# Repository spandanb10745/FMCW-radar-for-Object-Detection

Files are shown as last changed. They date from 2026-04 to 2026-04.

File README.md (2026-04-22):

# FMCW Radar for Object Detection 📡

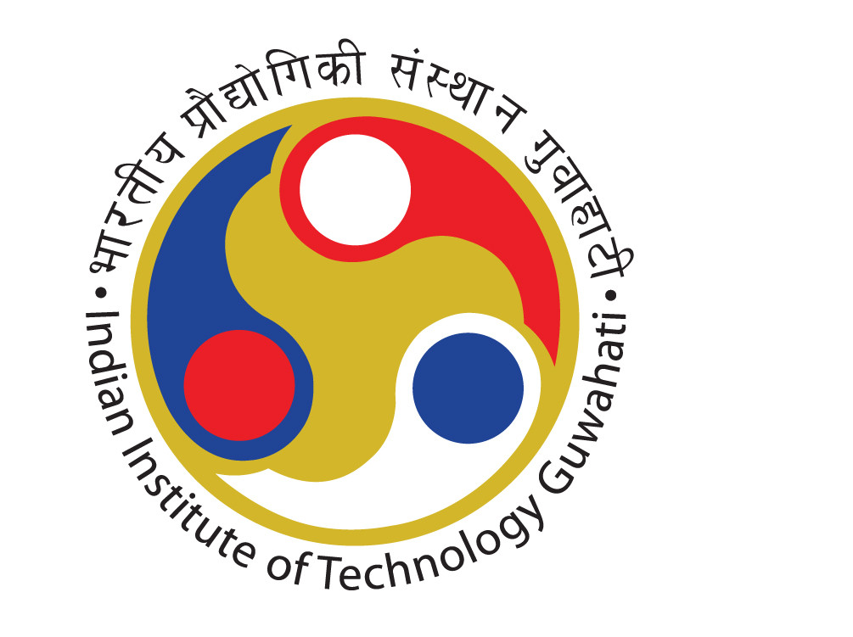
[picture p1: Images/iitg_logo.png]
IITG Logo

*Department of Electronics and Communication Engineering, Indian Institute of Technology, Guwahati*

This repository contains the hardware design, theoretical models, and digital signal processing (DSP) algorithms for a custom-built Frequency-Modulated Continuous Wave (FMCW) radar. The system is designed to detect both stationary distances and track moving targets (human radial velocity) using a 2.4 GHz center frequency.

## 📋 Table of Contents
* [Overview & Principles](#overview--principles)
* [Hardware Architecture](#hardware-architecture)
* [Signal Processing & DSP](#signal-processing--dsp)
* [System Integration](#system-integration)
* [Results](#results)
* [Future Improvements](#future-improvements)
* [Repository Structure](#repository-structure)
* [References](#references)
* [Acknowledgements](#acknowledgements)

---

## 🔬 Overview & Principles
Unlike pulsed radar, an FMCW radar transmits a continuous signal modulated over time. We use a linear triangular ramp to sweep the frequency from the start frequency to the stop frequency. 

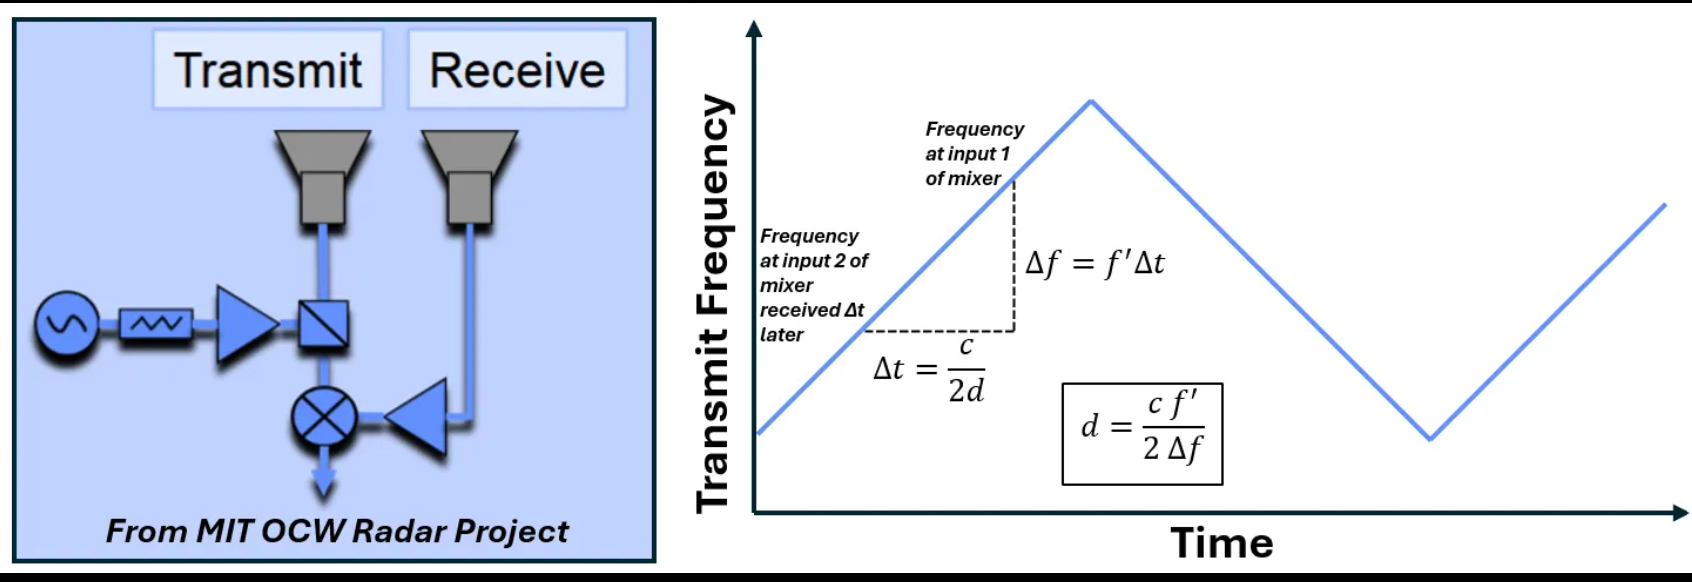
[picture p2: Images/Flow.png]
System Flow Diagram


When the transmitted signal reflects off a target, it returns after a time delay. By mixing the transmitted and received signals, we generate a "beat" frequency. The range of the target is directly proportional to this beat frequency:

$$R = \frac{c \cdot T_p \cdot f_b}{2 \cdot B}$$

Where $T_p$ is the sweep time (23 ms), $B$ is the bandwidth (~300 MHz), and $c$ is the speed of light.

---

## 🛠️ Hardware Architecture

### 1. Antennas
Custom-designed pyramidal horn antennas (WR340 waveguide standard) optimized for 2.4 GHz. 
* **Material:** 3D-printed PLA wrapped in conductive aluminum tape.
* **Design Generation:** The optimal dimensions were calculated using Balanis' iterative root-finding equations (see `Antenna/antenna_design.py`).

<p align="center">
  3D Printing Horn Antenna
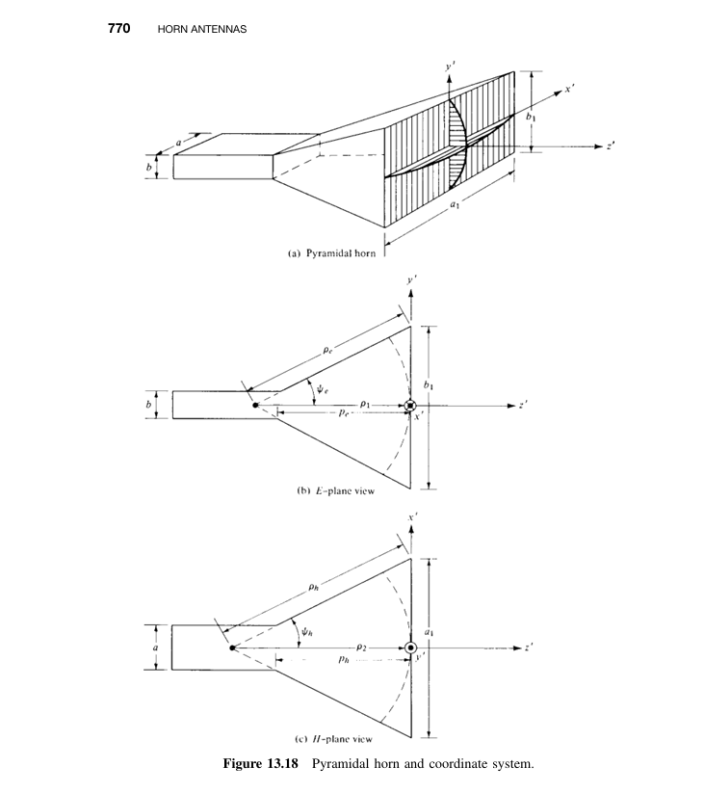
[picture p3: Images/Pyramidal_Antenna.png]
Pyramidal Antenna Dimensions
  
</p>

**Performance:** Testing confirmed a gain of -10 dB at 2.4 GHz. Orthogonal placement yields -42 dB isolation, mitigating TX-to-RX cross-talk.

<p align="center">
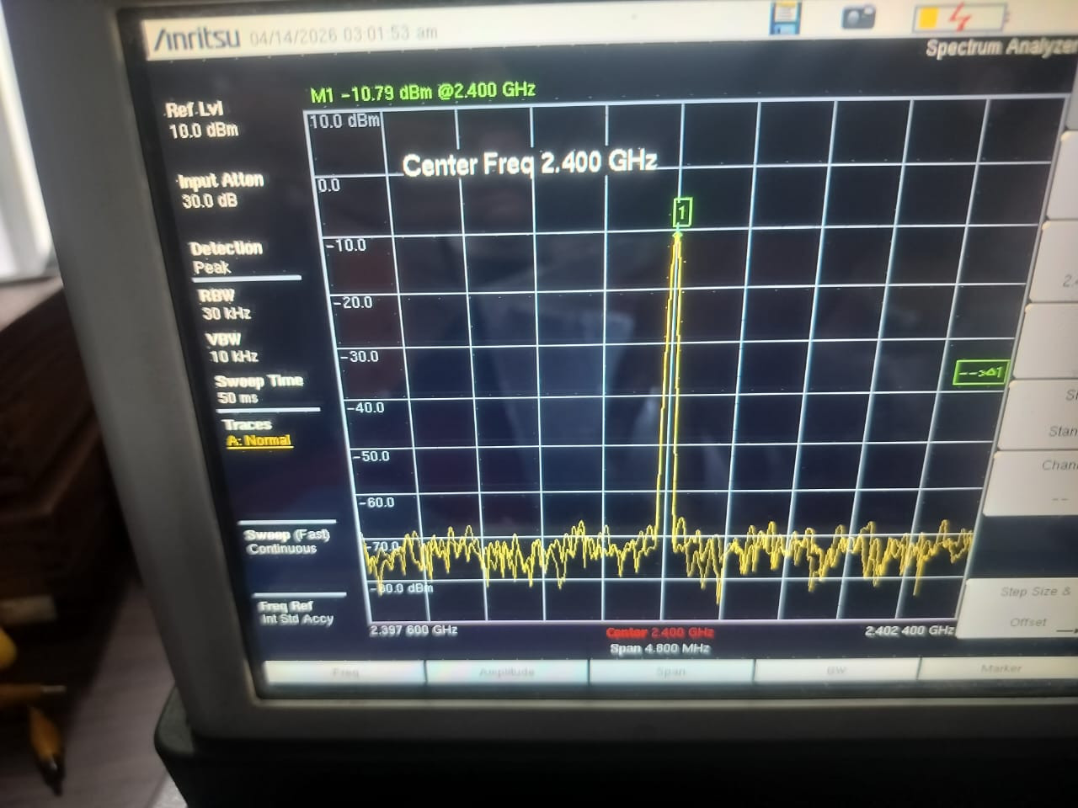
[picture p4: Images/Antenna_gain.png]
Antenna Gain
  
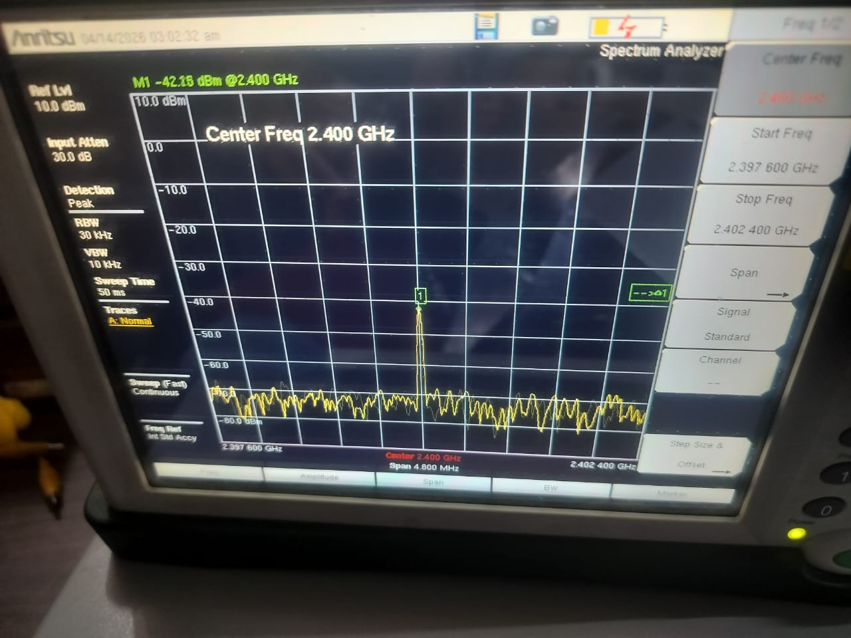
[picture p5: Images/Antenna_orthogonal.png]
Antenna Orthogonal
  
</p>

### 2. Modulation & RF Front-End
* **Ramp Circuit:** A custom triangle wave generator using an operational amplifier Schmitt trigger and integrator, biased at a 4.2V DC offset. This drives the VCO to generate the 2.4 GHz RF sweep.

**Ramp Circuit Design & Simulation:**
<p align="center">
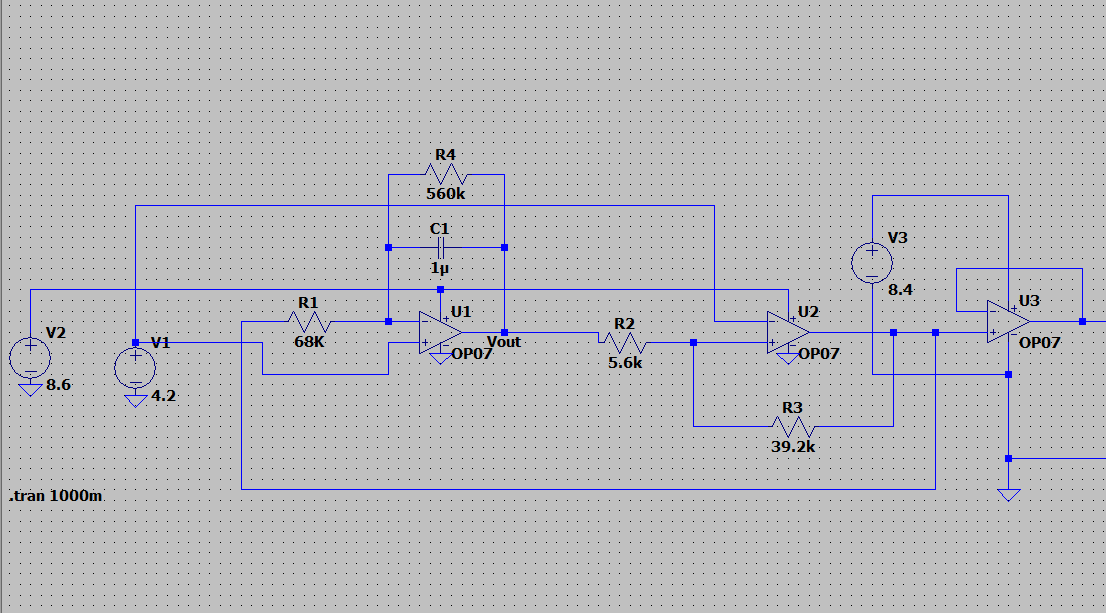
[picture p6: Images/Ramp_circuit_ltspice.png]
Ramp LTSpice
  
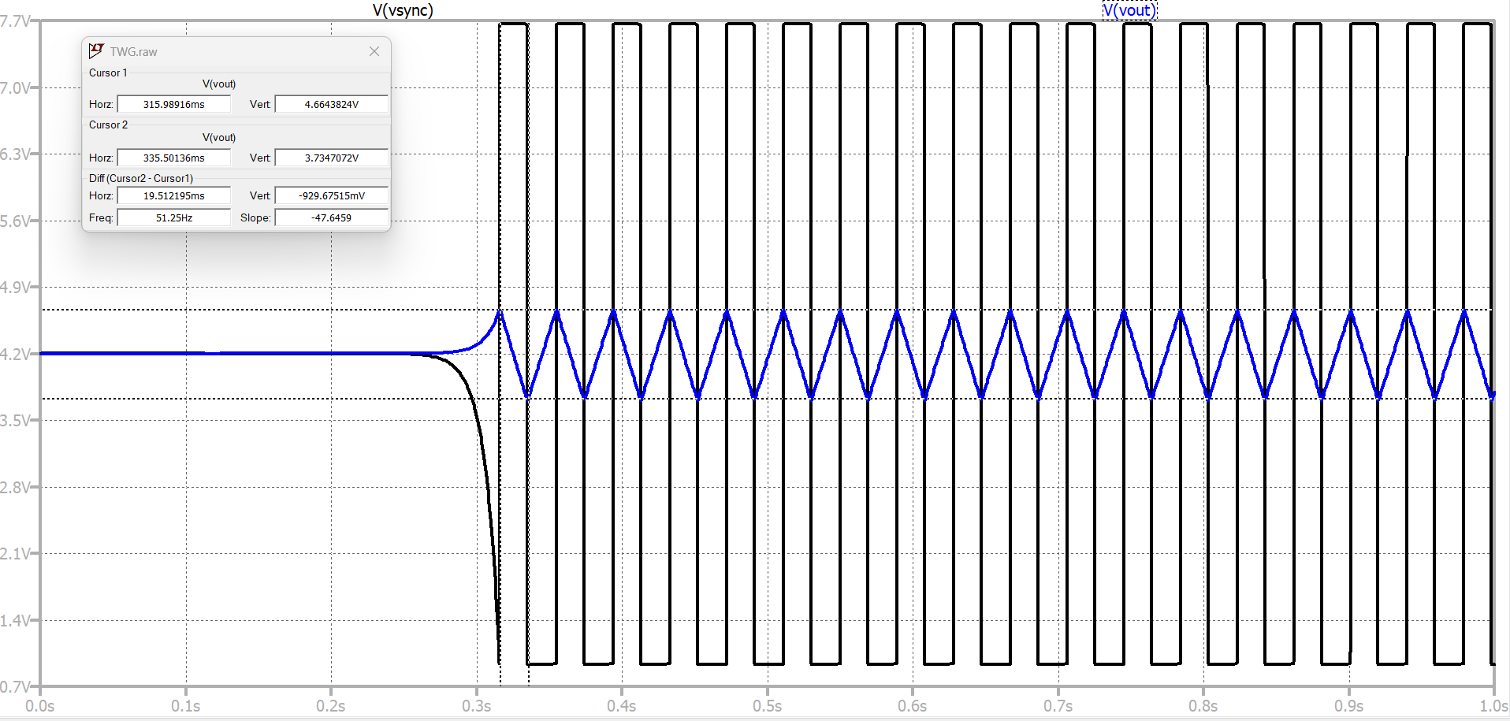
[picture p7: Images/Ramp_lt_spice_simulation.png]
Ramp Simulation
  
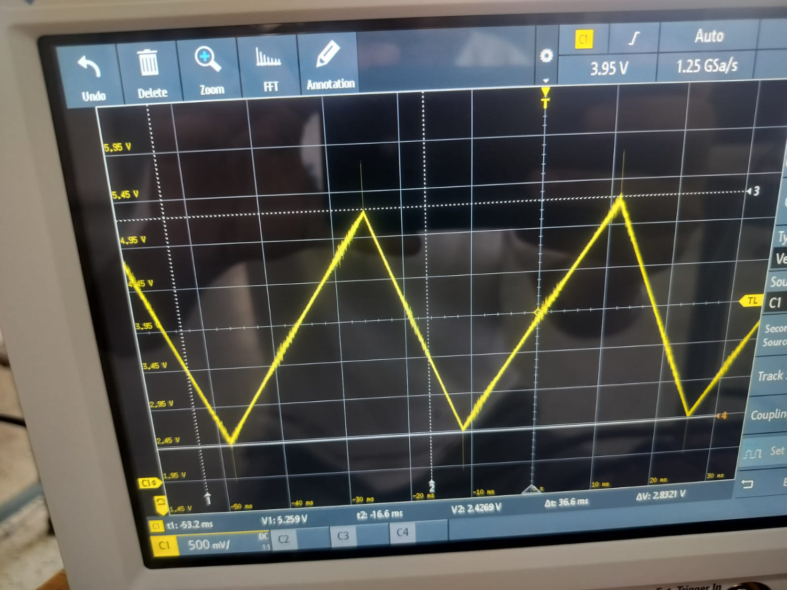
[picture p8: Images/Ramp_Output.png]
Ramp Output Oscilloscope
  
</p>

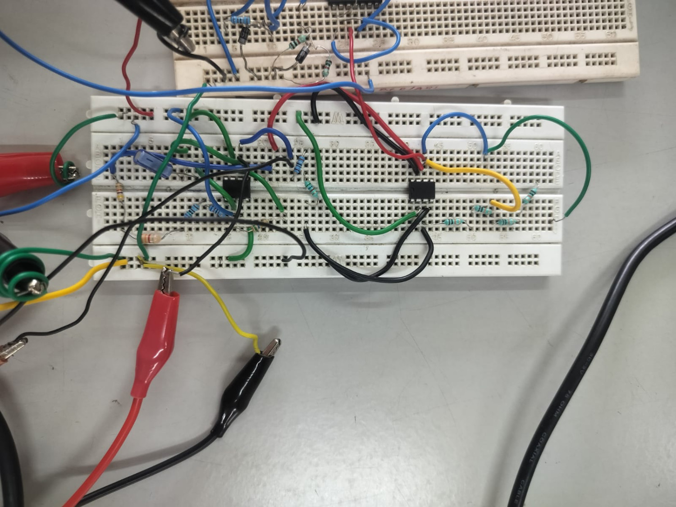
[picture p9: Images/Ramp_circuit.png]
Physical Ramp Circuit


*(Note: The RF front-end also utilizes a VCO, Power Splitter, Low Noise Amplifier, and Frequency Mixer. Refer to the project report for exact component numbers and specifications).*

### 3. Signal Conditioning
* **Thomas Biquad Low Pass Filter:** An orthogonally tunable active filter that simultaneously amplifies the weak beat signal and strips high-frequency noise.

<p align="center">
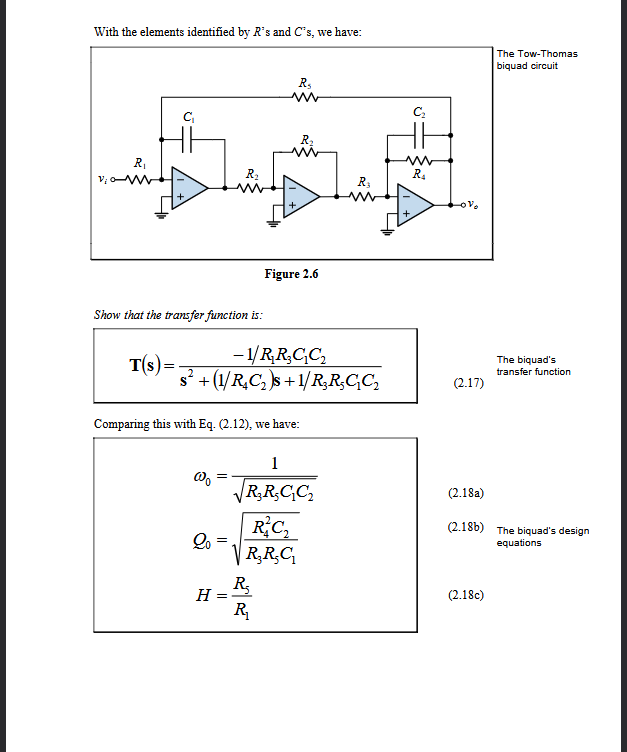
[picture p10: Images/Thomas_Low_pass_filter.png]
Thomas LPF Schematic
  
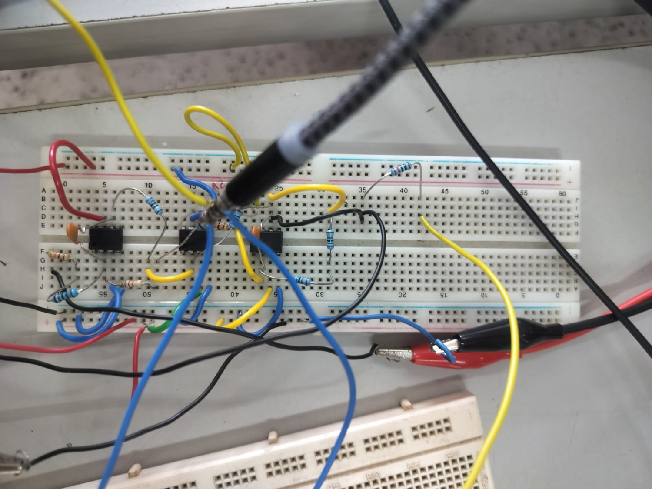
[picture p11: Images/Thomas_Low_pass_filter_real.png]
Thomas LPF Physical
  
</p>

* **Sync Circuit:** Attenuates and level-shifts the raw square wave from the Schmitt trigger into a 0V-centered, line-level synchronization pulse for the ADC.

<p align="center">
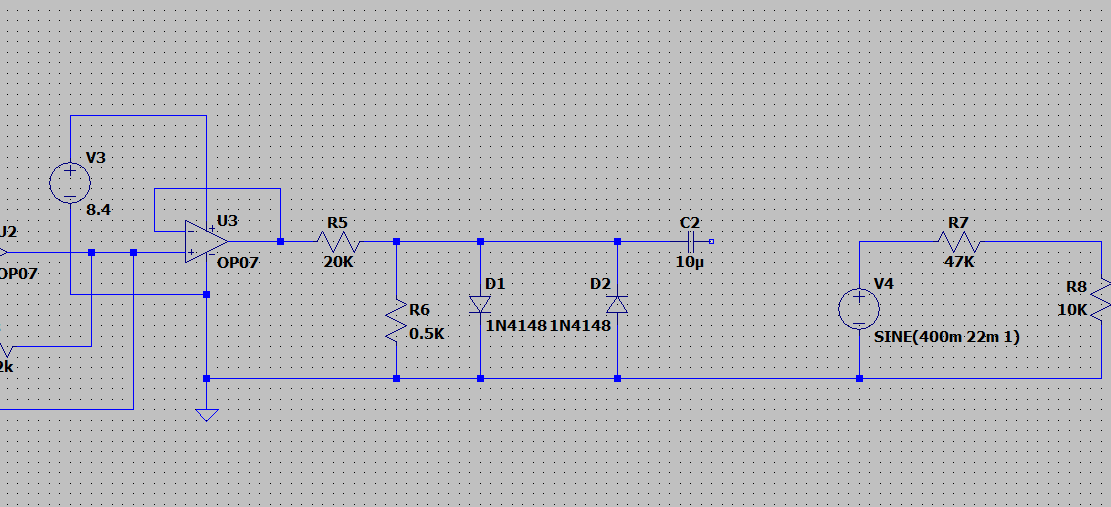
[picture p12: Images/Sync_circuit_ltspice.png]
Sync LTSpice Schematic
  
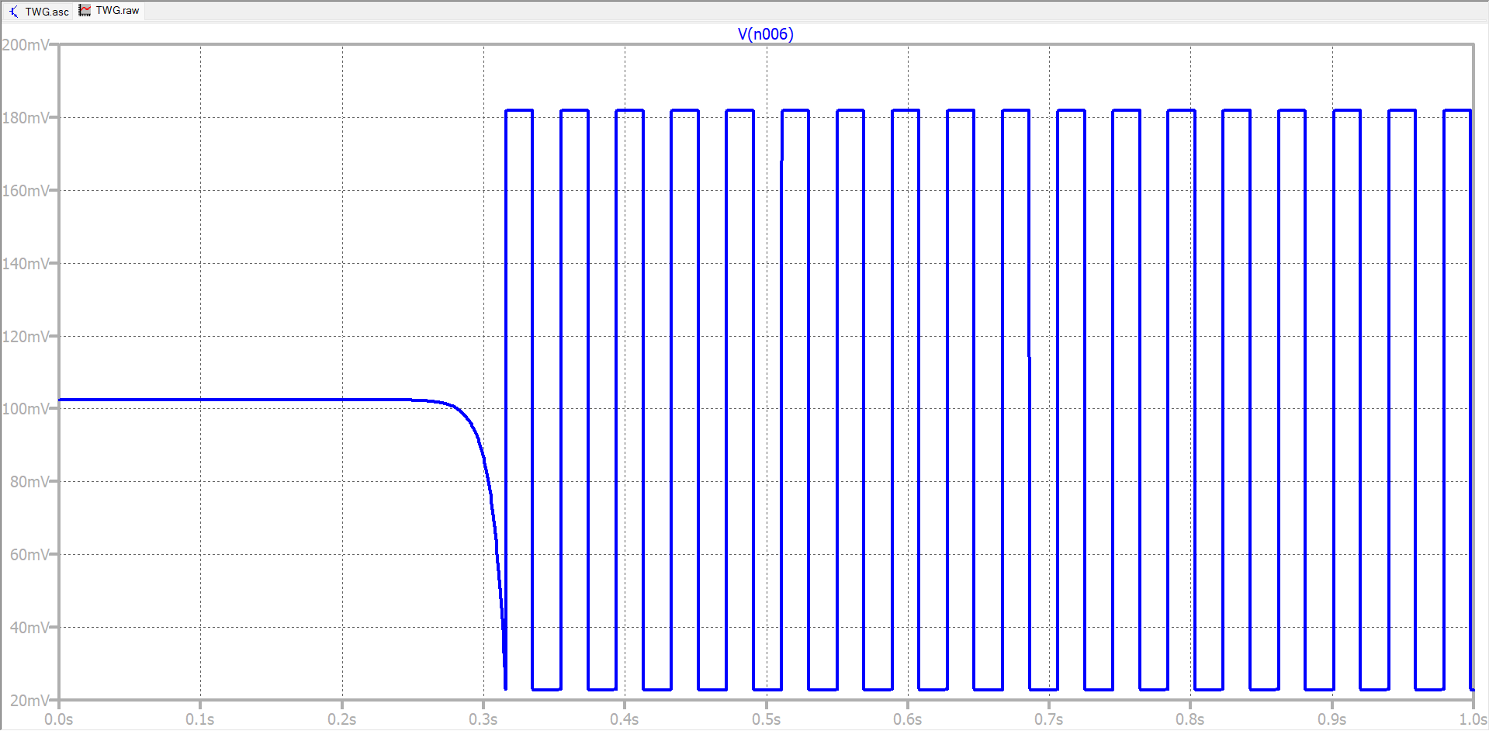
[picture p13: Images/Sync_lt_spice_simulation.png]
Sync Simulation
  
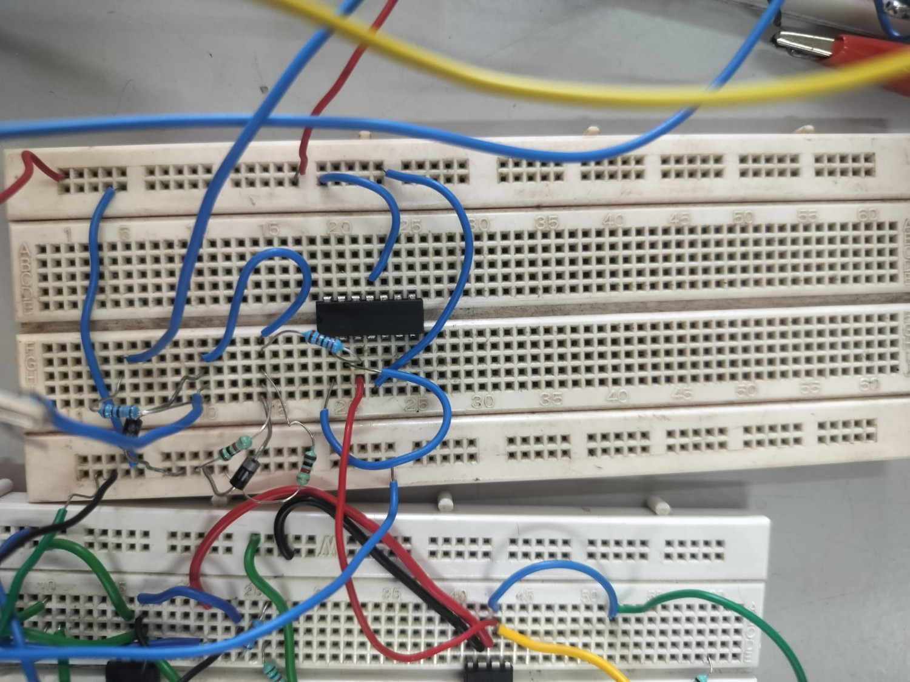
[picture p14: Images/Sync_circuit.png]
Sync Circuit Physical
  
</p>

---

## 🔌 System Integration

Integrating the radar required careful power management across four separate DC power sources and one split supply. The entire setup was monitored continuously using a 3-channel oscilloscope.

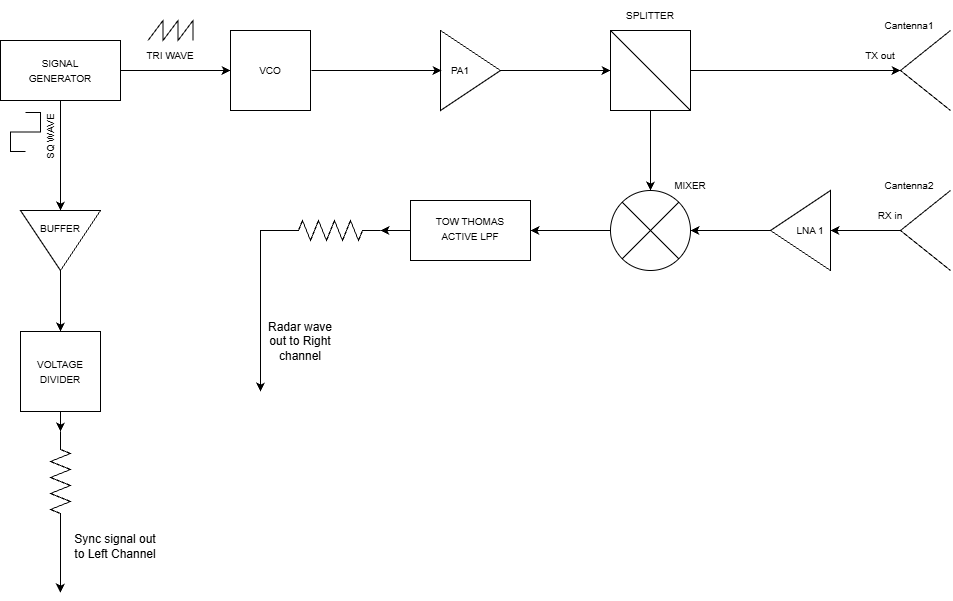
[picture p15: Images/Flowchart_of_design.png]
Flowchart of Design


<p align="center">
  Full Hardware Setup
  Testing Environment Setup
</p>

---

## 💻 Signal Processing & DSP
Analog-to-Digital Conversion is handled via a standard stereo TRS input (Left = Sync, Right = Radar Data) into a laptop. The raw `.wav` files are processed in MATLAB.

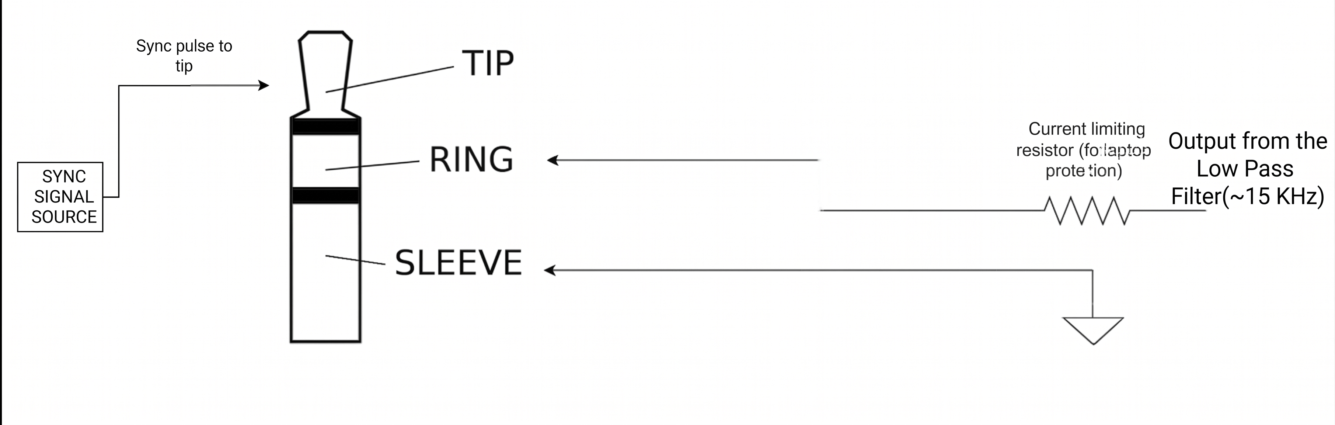
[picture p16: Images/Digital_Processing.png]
Digital Processing


* **Stationary Targets (RTI):** Pulse slicing is followed by an Inverse Fast Fourier Transform (IFFT) to convert beat frequency bins into physical distances, plotted as a Range-Time Intensity (RTI) heatmap.
* **Moving Targets (MTI):** Stationary clutter is mathematically erased by subtracting the arithmetic mean of all pulses. The peak range is tracked, smoothed, and differentiated to estimate velocity, followed by median filtering.

---

## 📊 Results

### Stationary Target Detection
Successfully detected structural boundaries (e.g., roof detection) with solid horizontal magnitude responses on the RTI plot.

<p align="center">
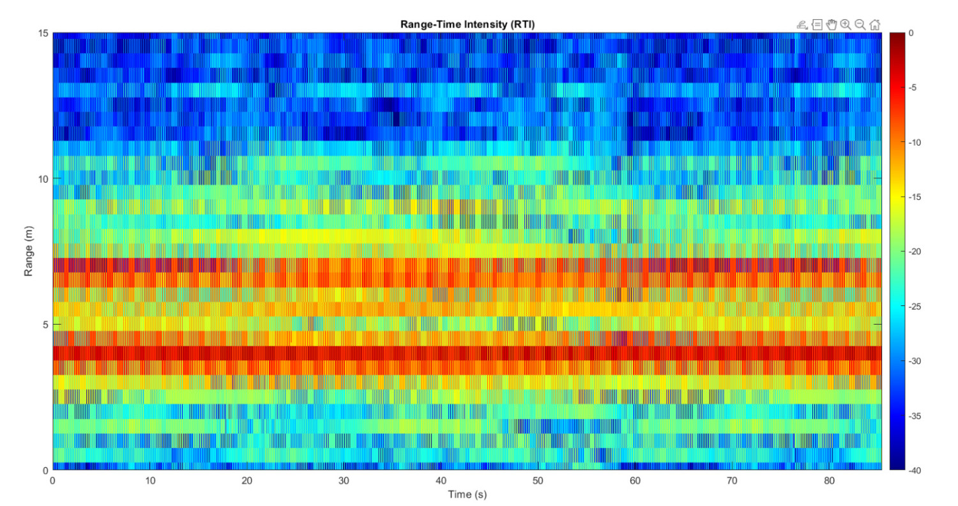
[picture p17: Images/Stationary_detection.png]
Stationary Full Range
  
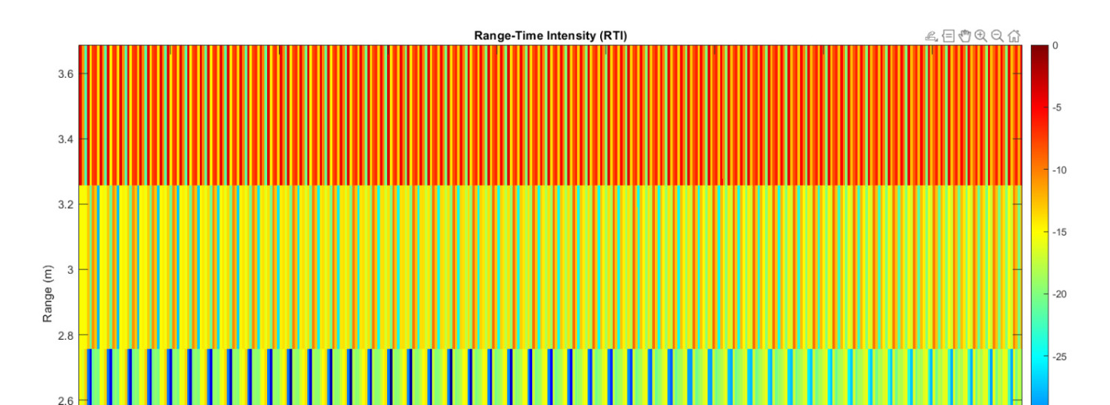
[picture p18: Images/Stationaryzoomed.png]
Stationary Zoomed
  
</p>

### Moving Object Detection
Clean isolation of human movement (walking towards and away from the radar) with an accurate, smoothed radial velocity trajectory, entirely unhindered by background static clutter.

<p align="center">
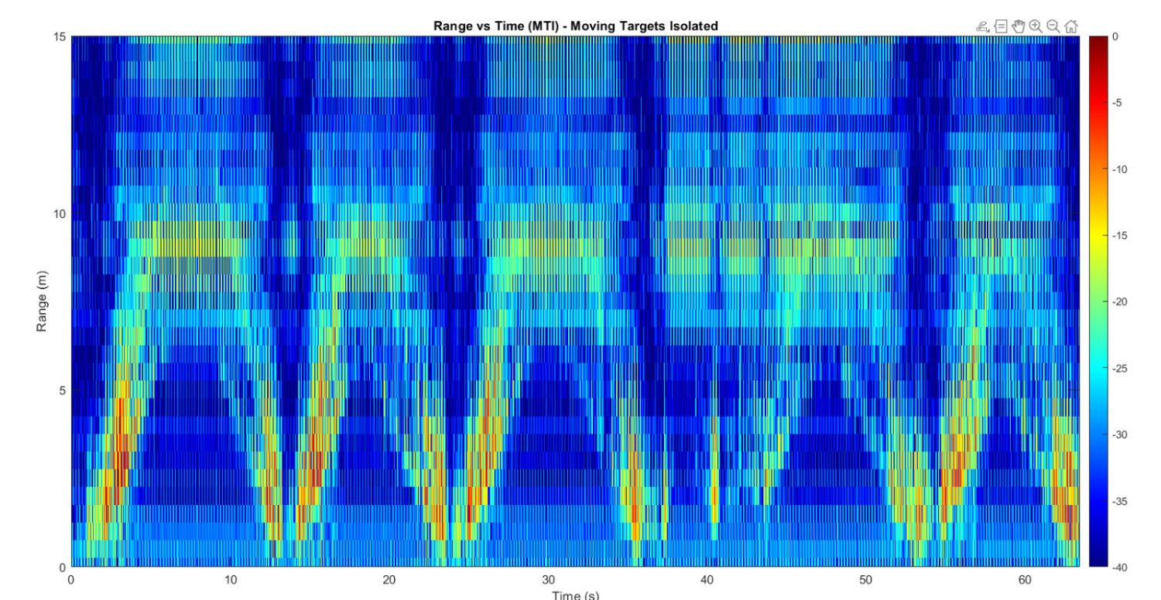
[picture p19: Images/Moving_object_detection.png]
Moving Object Detection MTI
  
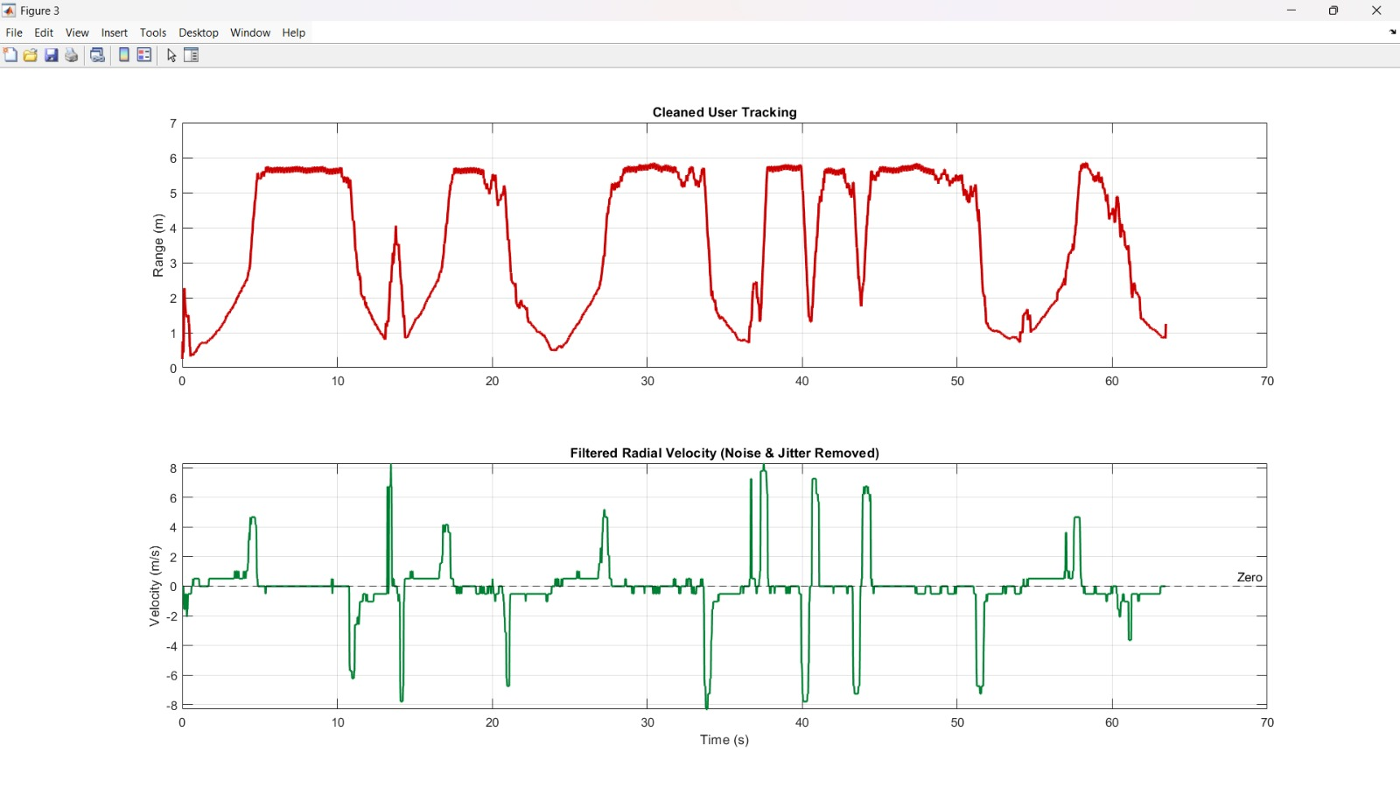
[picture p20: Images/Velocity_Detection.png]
Velocity Detection
  
</p>

---

## 🚀 Future Improvements
1.  **SoC Tape-Out:** Migrating from discrete components to a custom Radio Frequency Integrated Circuit (RFIC) with planar microstrip patch antennas to reduce parasitics and footprint.
2.  **Embedded Edge Processing:** Replacing the laptop soundcard with an ARM Cortex-M microcontroller (e.g., STM32H7) to perform real-time 1D FFTs using onboard SRAM.
3.  **Linearization:** Implementing a Fractional-N PLL synthesizer to correct thermal drift and ramp non-linearity at the frequency extremes.
4.  **Millimeter Wave (mmWave):** Scaling to 24 GHz, 60 GHz, or 77 GHz ISM bands for vastly improved range resolution and phased array Angle of Arrival (AoA) capabilities.

---
## 📚 References
1. **Instructables:** *FMCW Radar With 3D Printed Antennas.* Available at: [Instructables Guide](https://www.instructables.com/FMCW-Radar-With-3D-Printed-Antennas/)
2. **Constantine A. Balanis:** *Antenna Theory: Analysis and Design.* Wiley.
3. **Paul Horowitz and Winfield Hill:** *The Art of Electronics.* Cambridge University Press.

---

## 🤝 Acknowledgements
We would like to express our sincere gratitude to **Prof. Mahima Arrawatia**, Assistant Professor at IIT Guwahati, for her invaluable guidance, support, and mentorship, which were instrumental in making this project a success.

---

## 👥 Authors
* **Spandan Bharadwaj** (Roll No. 230102108)
* **Shreyas Sagar** (Roll No. 230102118)

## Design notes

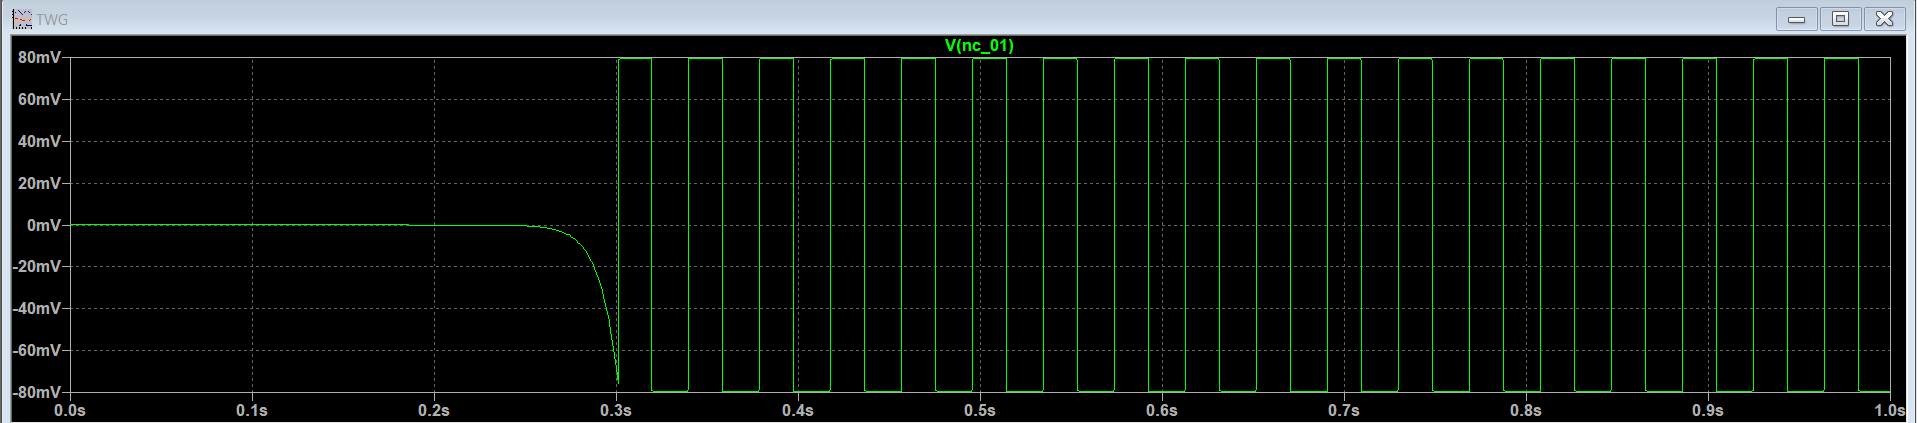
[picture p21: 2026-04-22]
Images/Sync_circuit_simultion_ltspice.png

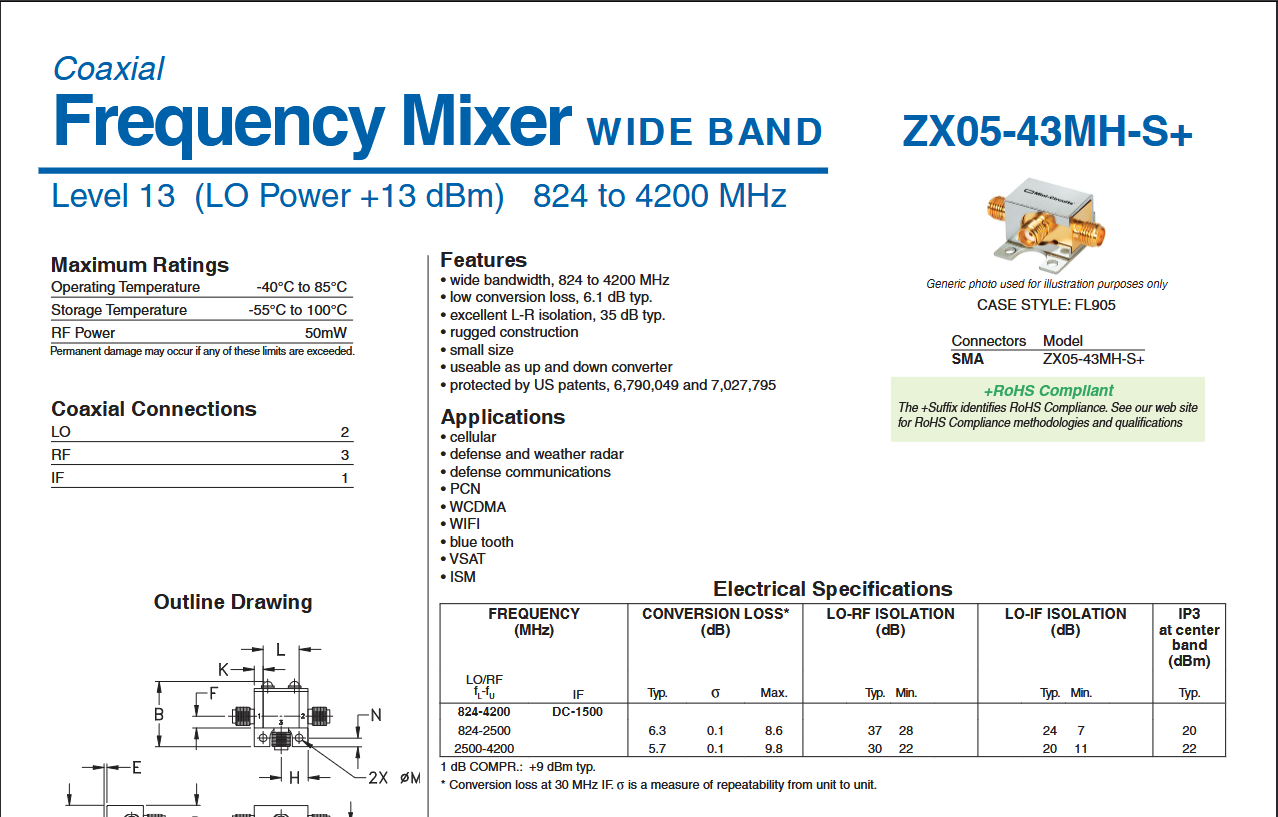
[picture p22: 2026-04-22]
Images/Frequency_Mixer.png

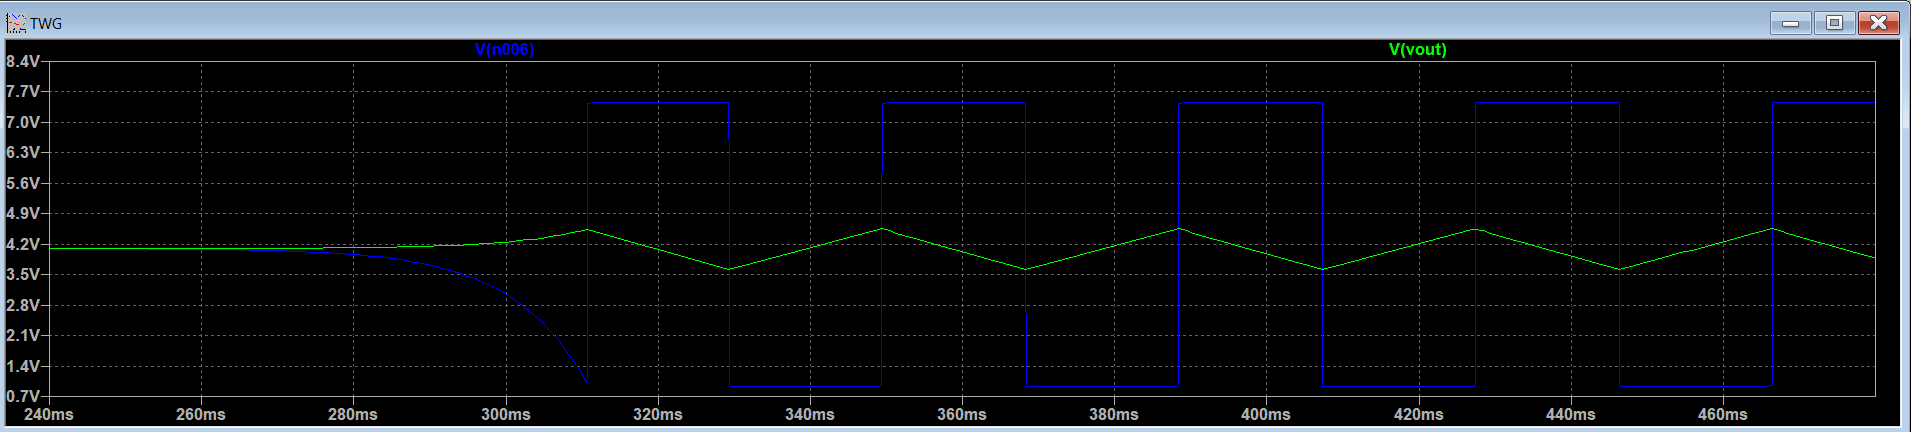
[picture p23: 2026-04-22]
Images/RAmp_ltspice_simulation.png

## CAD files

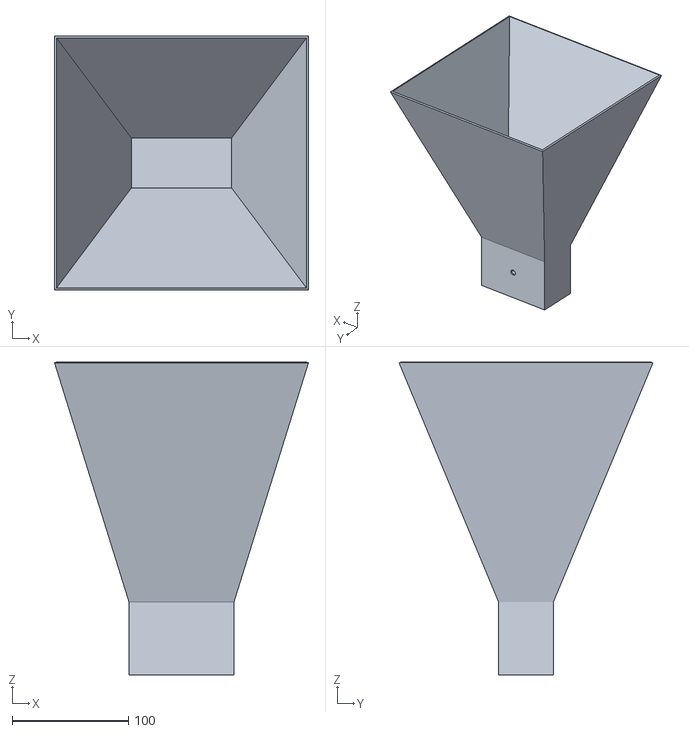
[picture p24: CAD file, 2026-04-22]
Antenna/s-band_horn_antenna_max_print_size.stl
218.3 x 218.2 x 269.0

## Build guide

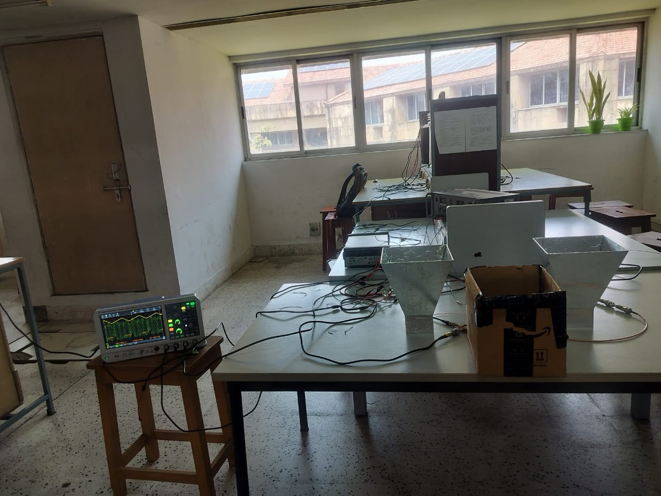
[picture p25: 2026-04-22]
Images/Setup.png

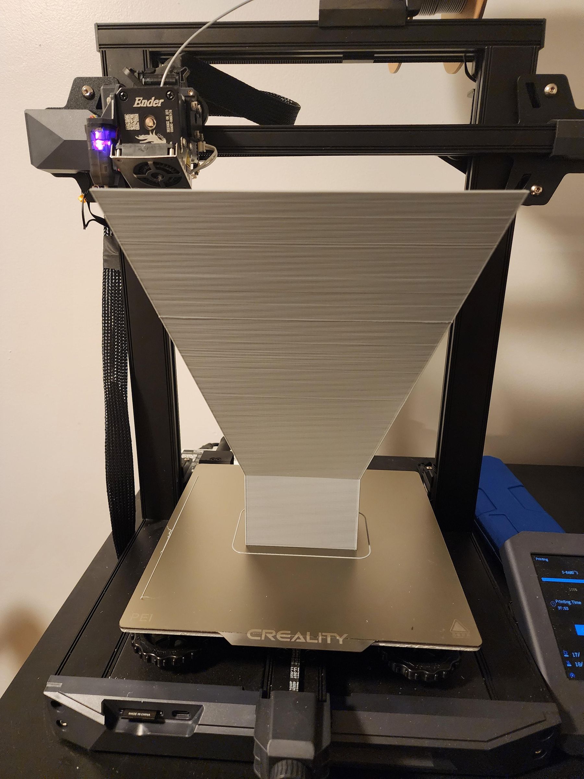
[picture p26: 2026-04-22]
Images/printing_horn_antenna.png

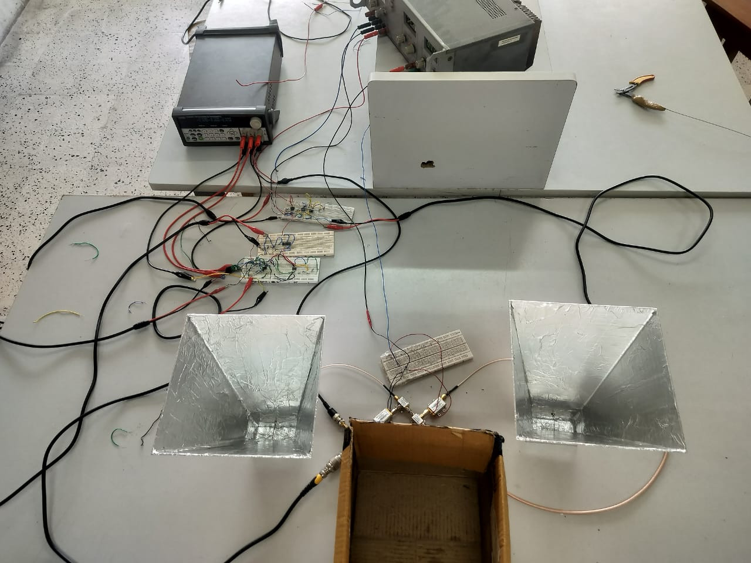
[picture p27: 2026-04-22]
Images/Full_setup.png
